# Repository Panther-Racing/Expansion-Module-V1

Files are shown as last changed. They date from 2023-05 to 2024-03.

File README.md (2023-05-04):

# Expansion-Module-V1
## Messaging Structure

| Message Structure||
|:--- |:--- |
|Base CAN ID:  | 0xF0 |
|Endianness | Big Endian |
|Message Length| 8 Bytes |
|Byte | Description of Contents |
|0 | Brake Temp [0-7] |
|1 | Brake Temp [8-9] / DPos[0-5] | 
|2 | DPos [6-9] / AUX 1 [0-3] |
|3 | AUX 1 [4-9] / Aux 2 [0-1]  |
|4 | Aux 2 [2-9] |
|5 | Firmware Version |
|6 | Compound ID |
|7 | Counter |

## Data Composition
|Data Name  |  Length(bits)  |  Position
|:---: |:---: |:---:
|Brake Temp. |  10 |  0-9
|DPos |  10 |  10-19
|Aux 1 |  10 |  20-29
|Aux 2 |  10 |  30-39 
|Firm. Vers  |  8 |  40-47
|Compound |  8 |  48-55
|Counter |  4 |  56-59

## Analog Sensor Wiring Table:
|Sensor Name |  PIN 
|:---: |:---:
| Brake Temp. | ADC0
| DPos | ADC1
| Aux 1 | ADC2
| Aux 2 |

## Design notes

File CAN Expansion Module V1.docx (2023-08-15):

# CAN Expansion Module V1

Document Number | | PR035_CANExpansionModuleV1_12JAN2023
Title | | CAN Expansion Module V1
Team Member / Engineer | | Raheel Farouk
Creation Date | | 12 JAN 2023
Prepared By | Date | Checked By | Change History
Raheel Farouk | 12JAN2023 | - | Initial Version
Raheel Farouk | 16JAN2023 | - | Added Endianness and Cleaned up formatting
Raheel Farouk | 06MAR2023 | - | Removed slip angle sensor and added Aux2
Patrick Murphy | 09MAR2023 | - | Added Descriptions of data and Setup information
Patrick Murphy | 21APR2023 | - | Added Changes Relating to Library change, data frame update and connections.
Patrick Murphy | 24MAY2023 | - | Updated to Reflect Canduino Deprecation. Added custom PCB descriptions. Reworked Sections.

# Purpose of Module

The purpose of the CAN Expansion Module is to convert desired analog sensor inputs into digital data on the CAN bus.

# Setup Guide

Setting up the Expansion Module requires a CAN ID for the expansion module and the sensors to be plugged into their corresponding spots on the module. The MoTeC firmware will decide between what input will be used for each function, for example brake temperature will select the brake temperature input but you will be able to choose between front and rear, left and right.

## Board Configuration

The initial version of the board was using the Canduino V3.1 which has the CS as Pin 10, the V3.0 is Pin 8, the custom PCB is 10. The Board Programming library for the Canduino’s and the Custom PCB.

### Custom PCB – V1

CS for SPI to CAN - 10. Programmed as Arduino Nano.

A custom PCB designed around the ATMEGA328P (16 MHz) with an MCP25625 (8 MHz) SPI to CAN controller at a 5v logic level. Includes 4 ADC (10 bit) pins with independent power and ground wires to reduce common wiring failure points for each sensor. The PCB has a selection bridge for enabling a 120 ohm CAN termination resistor if needed. Featuring a serial programming header for debugging and an ICSP interface for programming.

https://github.com/Panther-Racing/Expansion-Module-V1

### Canduino V3.1 (Deprecated)

CS for SPI to CAN (10). Programmed as ATMEGA328P using Board Library.

The Canduino V3.1 was an atmega328P with an attached MCP2515 and MCP2551 to allow communication onto a CAN network.

The Canduino possessed 8 ADCs, a 3v and 5v output, SPI interface and 10 Digital outputs. There is the option of having a CAN termination resistor through a solder bridge aswell as a chip select through a solder jumper.

More information on this can be found in the following locations.

This board has entered deprecated status from the manufacturer.

https://www.tindie.com/products/massivegroup/canduino-v31-atmega328p-with-can-bus/

https://github.com/MassiveButDynamic/canduino-v3.1

## Can Library Configuration

The library used to communicate with the MCP2515 as recommended by the Canduino is the Arduino-mcp2515 library. Previously the MCP_CAN library by coryjfowler was used however issues were encountered relating to significant transmit errors on the bus so this is no longer used.

## Analog Sensor Wiring

Sensor Name | PIN | Colors
Brake Temperature | ADC 0 | White - Yellow
DPOS | ADC 1 | White – Brown
AUX 1 | ADC 2 | White - Green
AUX 2 | ADC 3 | White – Black

# Messaging Structure

## SPI Message structure

Endianness | Big Endian
Message Length | 8
Byte | Contents*
Byte0 | Brake Temp (9-2)
Byte1 | Brake Temp (1-0) | DPOS (9-4)
Byte2 | DPOS (3-0) | Aux 1 (9-6)
Byte3 | Aux 1 (5-0) | Aux 2 (9-8)
Byte4 | Aux 2 (7-0)
Byte5 | Firmware Version
Byte6 | Transmit Error Counter (TEC)
Byte7 | Counter

*Note: The numbers in brackets are the bit numbers of the data stored in the byte. For example if Brake temp is a 10bit value, then the most significant first 8 bits of brake temp, Bits 9 to 2 will be stored in byte 1, then the remaining 2 bits will be stored in byte 1.

## Can Message Structure of Data

Base CAN ID: | 0x760 ; +1 ; +2 ; +3
| FL – 0x760 | | FR – 0x761
| RL - 0x762 | | RR – 0x763
Data Name* | | Length (Bits) | | Position in Message
| | | | Start | End
Brake Temp | | 10 | | 0 | 9
DPOS | | 10 | | 10 | 19
Aux 1 | | 10 | | 20 | 29
Aux 2 | | 10 | | 30 | 39
Firmware Version | | 8 | | 40 | 47
Transmit Error Counter (TEC) | | 8 | | 48 | 55
Counter | | 4 | | 56 | 59

*Note: that the Data will effectively be sent as unsigned integers with values in the range of 0 to 2^(length of bits). Any conversion of this information currently needs to be performed on the receiving end of the data.

# Additional Notes

Auxiliary sensor attached to things like steering position.

## Description of Firmware Version

The firmware version corresponds to the current version of the Module. This is represented in format the format of vXX.X. In the software this is programmed as a uint8_t type. To achieve the decimal position the firmware version must be 100 times the current version. For example if the current version of the module is v0.1 then the firmware version shall be 100*0.1 or 100.

## Description of Compound

Compound is unimplemented. To be used if the length of data the module transmits exceeds 8 bytes of information to allow more data extraction from the same CAN ID. On the MOTEC side of this program the compound ID is actually the TEC from the board.

## Description of Counter

Counter is a 4bit value used to determine if loss of transmission occurs. If observing transmission from the board this value shall go from 0 to 15 and rollover, if any value is missed while this is occurring then a loss of transmission has occurred and should be investigated.

## ADC

For the ATMEGA328P there are 6 ADC pins which are multiplexed to a single ADC at up to a 10bit accuracy.

Transmit Error Counter (TEC)

The TEC is read from the mcp2515 / 25625 registers using SPI. This describes the number of times that the controller has been broadcasting to the CAN bus but has detected that a value it sent was not properly sent. This can be seen using MOTEC via the “Compound ID”.

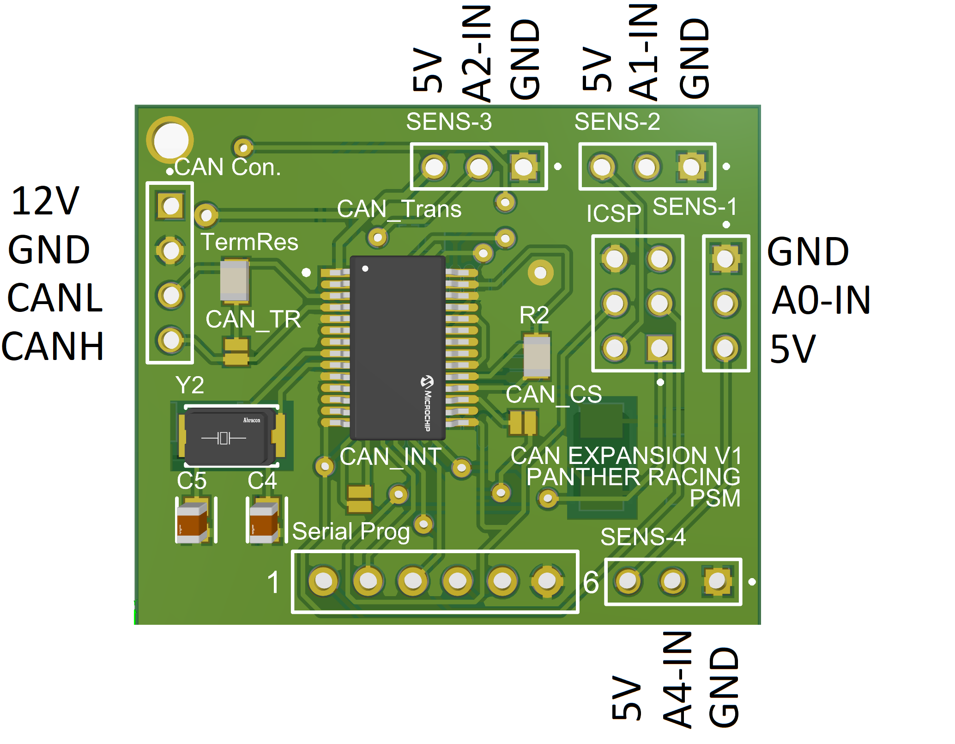
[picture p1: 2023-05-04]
HEADER-DIAGRAM.png

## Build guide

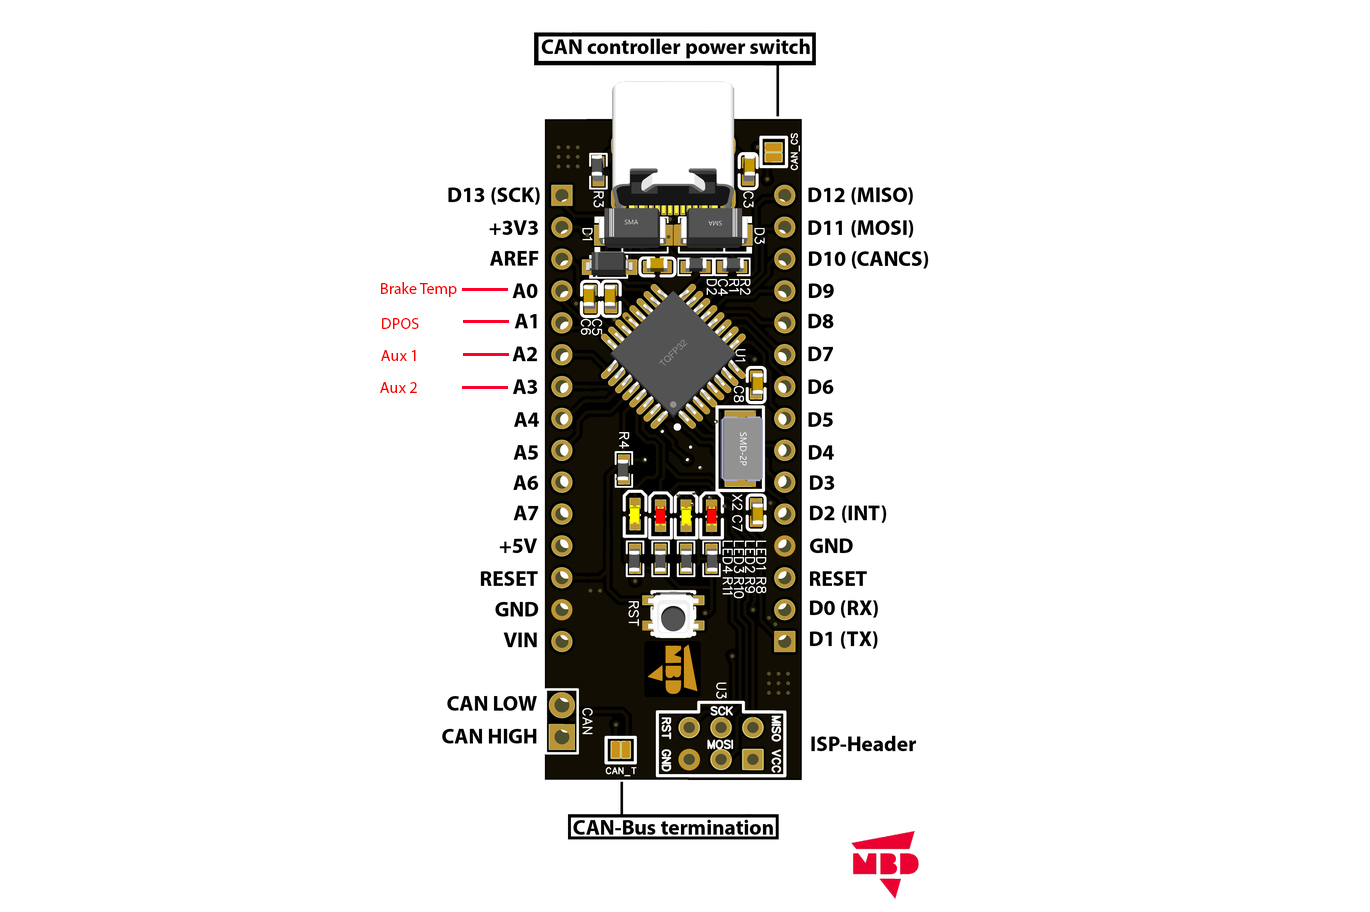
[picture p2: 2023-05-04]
Wiring.png

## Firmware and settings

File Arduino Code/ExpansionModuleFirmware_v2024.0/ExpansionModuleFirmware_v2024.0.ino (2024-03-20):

/* CAN Expanson Module Code
 *  Version 0.2
 * Made by Patrick Murphy 2023
 * Revised in 2024 by Raheel Farouk(raheelfarouk@pitt.edu/raheelfarouk@gmail.com)
 *
 * Repository https://github.com/Panther-Racing/Expansion-Module-V1
 *
 * Goals: 
 *  Use MCP25625(SPI to CAN) to take analog sensor readings and put data onto the CAN bus for logging purposes.
 * 
 * To Do: 
 *  Parametric BIT shifting function for formatting data lengths for adaptability to other applications
 *  Compound value
 * 
 *
 * Program Notes:
 *  CS pin is technically variable to setup
 *  CAN bus rate is variable to Setup
 *  MCP Clock is variable to setup
 *  Sensor Wiring is variable to setup
 *
 */


#include <SPI.h>
#include <mcp2515.h>
struct can_frame frame;

//Initial Variable Declarations
  // constants won't change:
  // Interval Declaration
    long interval = 100;  // interval at which to send HZ

    unsigned long previousMillis = 0; 

  //10 bit values
    unsigned int BrkTmp=0b0000000000;
    unsigned int DPos=0b0000000000;
    unsigned int Aux1=0b0000000000;
    unsigned int Aux2=0b0000000000;
  
  //8 bit values
    uint8_t TEC=0x00; // transmit error counters
    uint8_t firmwareversion= 0xF0; //Firmware version
      // because firmware version is represented as Vxx.xx, the firmware version needs to be 100 times the value
      // due to unsigned int, ie v0.10 ==> firmware version=10 => 0b00001010 ==> 0x0A
  
    uint8_t counter=0x00; // coms loss check


  // board Chip Select Pin for SPI to CAN chip  
    uint8_t CS=10;
    MCP2515 mcp2515(CS);
 


void setup() {
  interval = 1000/interval; //conversion from HZ to MS
  //Setting Pullups on ADC pins in use
  pinMode(A0,INPUT_PULLUP);
  pinMode(A1,INPUT_PULLUP);
  pinMode(A2,INPUT_PULLUP);
  pinMode(A3,INPUT_PULLUP);


  frame.can_id  = 0x761; //CAN ID
  /*
    FR-x760
    FL-x761
    RR-x762
    RL-x763
  */
  frame.can_dlc = 8;//Data lenght of frame
  //debug control    
  while (!Serial);
  Serial.begin(115200);
  
  mcp2515.reset();
  mcp2515.setBitrate(CAN_5000KBPS, MCP_8MHZ);
  mcp2515.setNormalMode();
  
}

void message1() {
  //ADC Value Aquisition
  BrkTmp=analogRead(A0);
  DPos=analogRead(A1);
  Aux1=analogRead(A2);
  Aux2=analogRead(A3);
  byte TEC=ReadReg(0x1C); // Reading the Transmit Error Counter(TEC) from the can transciever


  frame.data[0] = (BrkTmp>>2);//byte 1
  frame.data[1] = ((BrkTmp<<6 & 0xc0) | (DPos>>4 & 0x3F));//byte 2
  frame.data[2] = ((DPos<<4 & 0xF0) | (Aux1>>6 & 0x0F));//byte 3
  frame.data[3] = ((Aux1<<2 & 0xFc) | (Aux2>>8 & 0x03));//byte 4
  frame.data[4] = Aux2;//byte 5
  frame.data[5] = firmwareversion;
  frame.data[6] = TEC;
  frame.data[7] = counter; 

  mcp2515.sendMessage(&frame);
}


void loop() 
{

   unsigned long currentMillis = millis();
  if (currentMillis - previousMillis >= interval) 
  {
    // save the last time you sent
    previousMillis = currentMillis;

    //counter setup
    if (counter<15){
      counter=counter+1;// increment counter everytime we send message so we can observe data loss occurence, rolls over at 2^8-1 to 0
    }
    else
    {
      counter=0;
    }

    //Message function
    message1();

  }
}

byte ReadReg (byte Reg){
  // function that reads a single byte message from a specified register, 
  digitalWrite(CS,LOW); // send SOC
  SPI.transfer(0b00000011); //say read to device
  SPI.transfer(Reg); //saying target register
  byte output=SPI.transfer(0x00); //reading from target register
  digitalWrite(CS,HIGH); // send EOC
  return output;
}

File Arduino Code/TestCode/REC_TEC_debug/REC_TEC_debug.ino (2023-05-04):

/* REC and TEC debug
 *  Version
 * Made by Patrick Murphy
 *
 * Repository https://github.com/Panther-Racing/Expansion-Module-V1
 *
 * Goals: 
 *  DEBUG CAN compatability faults by read error counters to determine fault device
 * 
 * need to read REC and TEC
 * Error active if both REC and TEC<128
 * Error passive if (REC or TEC) >= 128
 * if TEC >255 bus off fault
 *    Recovers when 128 counts of 11 consecutive recessive bits
      ie bus idle for 128x11 bit times
      error interrupt service routine might affect
TEC register: 1Ch
REC register: 1Dh
error flag register: 2Dh
 */


#include <mcp_can.h>
#include <SPI.h>

//Initial Variable Declarations
  uint8_t CSpin=10;
  MCP_CAN CAN0(CSpin);     // Set CS to pin 10
  //10 bit values
  unsigned int BrkTmp=0b0000000000;
  unsigned int DPos=0b0000000000;
  unsigned int SlpAgl=0b0000000000;
  unsigned int Aux=0b0000000000;

  //8 bit values
  uint8_t compound=0x00; 
  uint8_t firmwareversion= 0x0A; //Firmware version
  // because firmware version is represented as Vxx.xx, the firmware version needs to be 100 times the value
  // due to unsigned int, ie v0.10 ==> firmware version=10 => 0b00001010 ==> 0x0A
  uint8_t counter=0x00; // coms loss check


  uint16_t CAN_ID  = 0x0701;// Device CAN ID
  /*
FR-x0700
FL-x0701
RR-x0702
RL-x0703
  */


  unsigned long previousMillis = 0;  // will store last time LED was updated

  // constants won't change:
  const long interval = 20;  // interval at which to blink (milliseconds)

  
void setup()
{
  pinMode(A0,INPUT_PULLUP);
  pinMode(A1,INPUT_PULLUP);
  pinMode(A2,INPUT_PULLUP);
  pinMode(A3,INPUT_PULLUP);
  
  Serial.begin(115200);

  // Initialize MCP2515 running at 16MHz with a baudrate of 500kb/s and the masks and filters disabled.
  if(CAN0.begin(MCP_ANY, CAN_1000KBPS, MCP_8MHZ) == CAN_OK) Serial.println("MCP2515 Initialized Successfully!");
  else Serial.println("Error Initializing MCP2515...");

  CAN0.setMode(MCP_NORMAL);   // Change to normal mode to allow messages to be transmitted
}

byte data[8] = {0x00, 0x00, 0x00, 0x00, 0x00, 0x00, 0x00, 0x00};

void loop()
{ 
  //Data Value Aquisition
  BrkTmp=analogRead(A0);
  DPos=analogRead(A1);
  SlpAgl=analogRead(A2);
  Aux=analogRead(A3);
  // debugging lines
  /*
  Serial.println("BrkTmp");  
  Serial.println(BrkTmp);

  Serial.println("DPOS");
  Serial.println(DPos);

  Serial.println("SLPAGL");
  Serial.println(SlpAgl);

  Serial.println("AUX");
  Serial.println(Aux);
  delay(500);
  */

      
  //Formatting data so 10 bit and 8 bits are stored in segments of 8 bits for SPI transfer
  data[0] = (BrkTmp>>2);//byte 1
  data[1] = ((BrkTmp<<6 & 0xc0) | (DPos>>4 & 0x3F));//byte 2
  data[2] = ((DPos<<4 & 0xF0) | (SlpAgl>>6 & 0x0F));//byte 3
  data[3] = ((SlpAgl<<2 & 0xFc) | (Aux>>8 & 0x03));//byte 4
  data[4] = Aux;//byte 5
  data[5] = firmwareversion;
  data[6] = compound;
  data[7] = counter; 

  //Sending data to MCP25625 chip
  // Standard can frame with 8bytes of data


  //Debugging the REC and TEC counter by reading it then displaying to serial
  byte REC=ReadReg(0x1D);
  byte TEC=ReadReg(0x1C);
  byte ER_Mode=ReadReg(0x1C);
  Serial.print("REC counter:");
  Serial.print(REC);
  Serial.print(",");
  Serial.print("TEC counter:");  
  Serial.print(TEC);
  Serial.print(",");
  //Error mode printout
  Serial.print("Error Mode:");
  Serial.println(ER_Mode,BIN);




  unsigned long currentMillis = millis();
  if (currentMillis - previousMillis >= interval) {
    // save the last time you blinked the LED
    previousMillis = currentMillis;
    //Serial.println((DPos>>4 & 0x3F),BIN);
     
     /*
     for (int i=0; i<8; i++)
      {
        Serial.println(data[i],HEX);
      }
      */
    if (counter<15)
    {
      counter=counter+1;// increment counter everytime we send message so we can observe data loss occurence, rolls over at 2^8-1 to 0
    }
    else
    {
      counter=0;
    }
    byte sndStat = CAN0.sendMsgBuf(CAN_ID, 0, 8, data);
    /*
    if(sndStat == CAN_OK)
    {
      Serial.println("Message Sent Successfully!");
    } 
    else
    {
      Serial.println("Error Sending Message...");
    }
    */
  //delay(50);   // send data per 100ms
  }
  
}

byte ReadReg (byte Reg){
  // function that reads a single byte message from a specified register, 
  digitalWrite(CSpin,LOW); /  / send SOC
  SPI.transfer(0b00000011); //say read to device
  SPI.transfer(Reg); //saying target register
  byte output=SPI.transfer(0x00); //reading from target register
  digitalWrite(CSpin,HIGH); // send EOC
  return output;
}
/*********************************************************************************************************
  END FILE
*********************************************************************************************************/

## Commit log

2023-03-07 Update to code to represent Canduino and fix car related errors
    Updated the MCP message speed to represent what is running on the car.
    Updated the MCP clock frequency to represent canduino's assembly.
    Reworked bit shifting to properly assemble messages based off of MSB and LSB.
    Changed how message timing works to be time based rather than length of time to complete code functions.
    Changed counter to be a 4 bit value.
    [ExpansionModuleFirmware_v0.1.ino]
2023-03-12 Added wiring pic and update notes
    Added small note on ADC
    added incomplete wiring picture
2023-03-21 Updating Code
    added pullup state for ADC inputs in case of line failure,
    Added AUX input
    [ExpansionModuleFirmware_v0.1.ino]
2023-03-22 initial push
    using Live telemetry hardware v3 as starting reference
    [CANExpansionV1.PrjPcb, Microprocessor Module (328).SchDoc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]
2023-03-23 Added Jumper Library, Removed extraneous connections
    Added Sparkfun jumper library for easy cut/include termination resistors.
    Removed extra header and organized schematic
    [Microprocessor Module (328).SchDoc, Microprocessor Module (328)_1.PcbDoc]
2023-03-24 Renamed Schematic to project
    [CAN Expansion V1.SchDoc, CANExpansionV1.PrjPcb, Microprocessor Module (328).SchDoc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]
2023-03-24 Updated SCH name
    [CAN Expansion V1.SchDoc]
2023-03-25 Adding debug code
    Code is intended to aid in debugging issues by reading registers directly from the CAN chip over SPI not using a library
    Currently just reads the config register
    [TestCode.ino]
2023-03-26 Smaller Board
    [CAN Expansion V1.PcbDoc, CAN Expansion V1.SchDoc, CANExpansionV1.PrjPcb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]
2023-03-28 updated caps, added routing of tracks
    [CAN Expansion V1.PcbDoc, CAN Expansion V1.SchDoc, Copy of CAN Expansion V1 copy.PcbDoc]
2023-03-29 Added Ground POUR, JLCPCB Rules checked
    Needs to be reviewed then should be production ready!
    Added Ground Pour on Top and Bottom Layer.
    Rule checked and modified to JLCPCB assembly spec.
    Routed tracks
    [CAN Expansion V1.PcbDoc, CAN Expansion V1.SchDoc, CANExpansionV1.PrjPcb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]
2023-03-30 update cs pin
2023-03-31 Reworked board layout
    Replaced SPI with Serial programmer.
    reworked positioning to bring oscillators closer to chips.
    Added cutout to ground pour for oscillators.
    [CAN Expansion V1.PcbDoc, CAN Expansion V1.SchDoc]
2023-03-31 update ground labeling
    updated ground labeling on CAN chip
    [CAN Expansion V1.PcbDoc, CAN Expansion V1.SchDoc]
2023-04-09 Updated for final rev of code
    fixed issue with can id not being stored properly.
    Added can ids for car setup
    Removed serial debug printing
    [ExpansionModuleFirmware_v0.1.ino]
2023-04-10 Added board version printout text
    added v1 desc. to top overlay layer
    [CAN Expansion V1.PcbDoc, CAN Expansion V1.SchDoc]
2023-04-10 added ground trace
    [CAN Expansion V1.PcbDoc]
2023-04-10 fixed ground pour
    ground pour connection now properly connects to MCU
    [CAN Expansion V1.PcbDoc]
2023-04-14 added transceiver state debugging
    to enable discovering of what causes CAN bus issue implemented debug lines to check and display the transmit and receive error counters as well as the error state register, will require the chip to be plugged in to a debugger and the car bus for active testing on the car.
    [REC_TEC_debug.ino]
2023-04-18 board export
    fixed board export
    [CAN Expansion V1.GBL, CAN Expansion V1.GBO, CAN Expansion V1.GBP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]
2023-04-18 added functionality diagram to project
    new functionality diagram covering I/O, power, and minor specifications of board
    [CANExpansionV1.PrjPcb, Functionality Diagram.SchDoc]
2023-04-20 Created Firmware Version 2
    Replaced CAN_MCP library with MCP2515 library
    Replaced Compound ID data with Transmit Error Counters (TEC) from SPI to CAN chip
    Updated firmware version to 2
    changed send interval control to HZ input from ms input
    [ExpansionModuleFirmware_v0.2.ino]
2023-04-21 Debug code, Fixed CS
    Fixed CS and CSpin declaration.
    added I diagram test code
    [Idiagram.ino]
2023-05-24 Documentation Update
    Added examples for counter.
    updated to add custom PCB and reflect deprecated status of canduino.
    [Documentation Examples.xlsx]
2024-03-20 Update CAN Bus rate
